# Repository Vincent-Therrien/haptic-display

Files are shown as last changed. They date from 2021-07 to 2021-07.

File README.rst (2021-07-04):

haptic-display
==============

A haptic display prototype for displaying tactile graphics

*Haptic* or *tactile* displays are designed to make images accessible for
visually impaired people. A surface acts as a screen whose elements can be
elevated or lowered to compose pictures accessible through touch.

High prices make this technology unaffordable to many consumers. This project
demonstrates a haptic display prototype with a low manufacturing cost
(inferior to 100 Canadian dollars) that achieves a ten by ten pixel resolution.

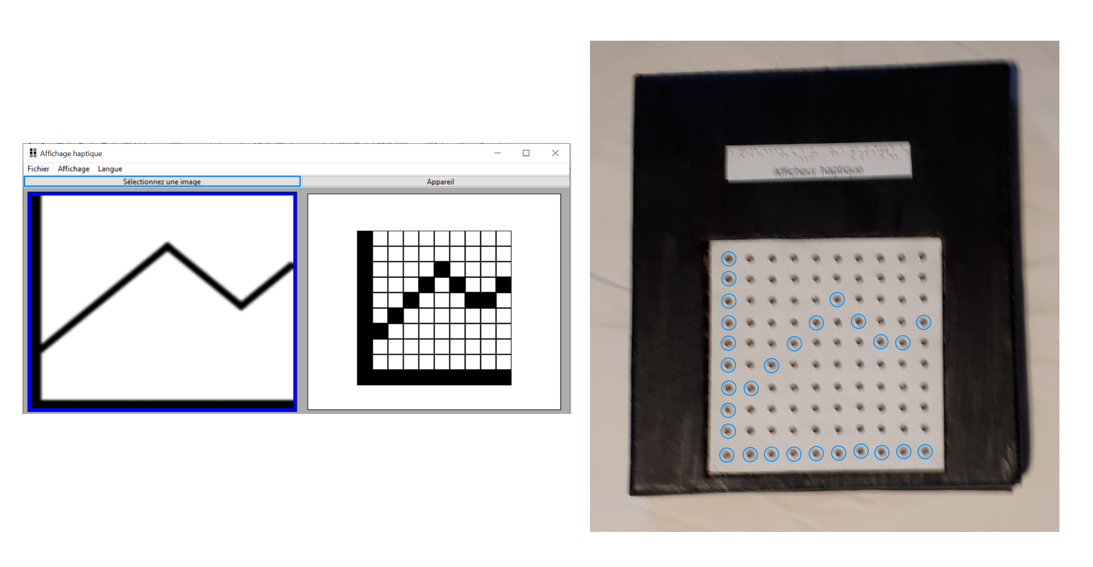
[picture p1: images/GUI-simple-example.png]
Haptic display demonstration with the application and the device


   Use case of the haptic display. The GUI (left) is used to select an image
   and adapt it to the display's resolution. The device (right) displays the
   image - picture elements in high position are highlighted with blue circles.

Project Components
------------------

The project comprises a *device* that displays images and a
*software application* used to upload images to the device. More precisely,

- The device is made of three modules:

  - A *mechanism* controlled with electrical motors manipulates the position
    of picture elements on the display.
  - An *electrical circuit* controls the rotation of motors through H-bridges.
    The circuit plans are available in the "device" directory.
  - An *embedded program* executed on a microcontroller controls power supply

- The application contains two main modules:

  - A graphical user interface, fully accessible with a keyboard and
    compatible with screen readers, is used to select images.
  - An OpenCV-based image manipulation script modifies images to adapt them
    to the display's resolution

Running the Application
-----------------------

The software application is multi-platform and can be used on any system that
support Python, WxWidgets and OpenCV. To run it, go the the
"haptic-display/application" directory, install all required
components (in a virtual environment, preferably) and launch the script
"haptic.py". On Windows,

.. code-block::

   py -m venv venv
   venv\Scripts\activate
   pip install -r application\requirements.txt
   py application/haptic.py

On UNIX,

.. code-block::

   python3 -m venv venv
   source venv/bin/activate
   pip install -r application/requirements.txt
   py application/haptic.py

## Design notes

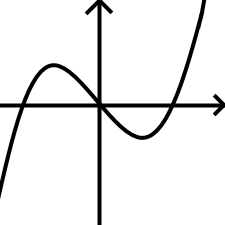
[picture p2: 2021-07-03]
application/assets/examples/third_degree.png

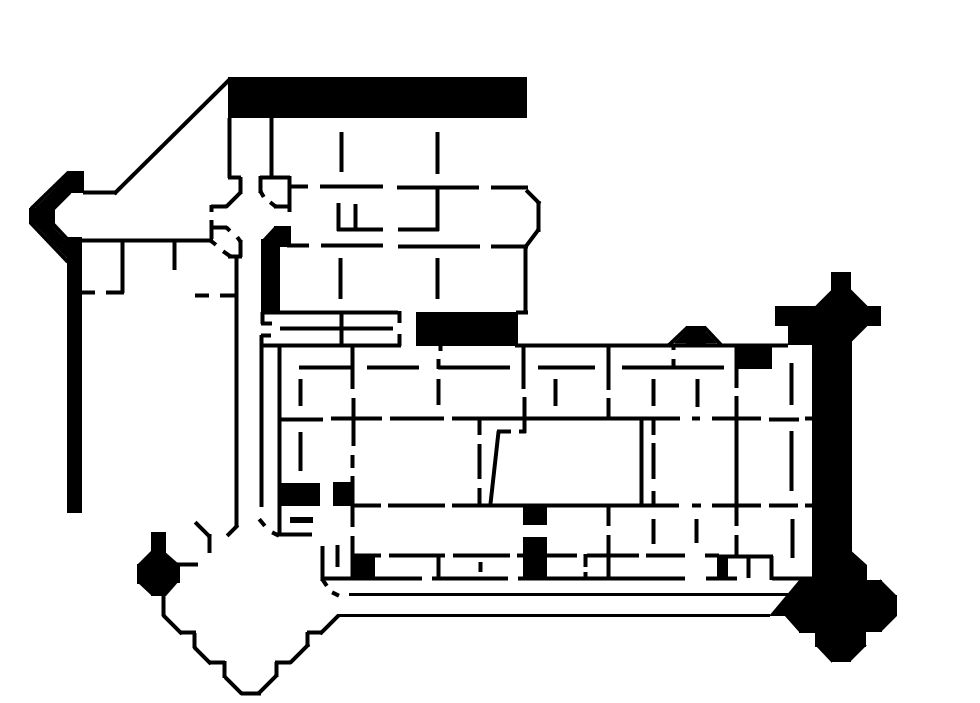
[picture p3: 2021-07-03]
application/assets/examples/mbam_floor_plan.png

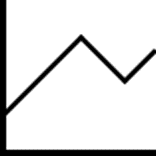
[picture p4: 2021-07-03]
application/assets/examples/linear.png

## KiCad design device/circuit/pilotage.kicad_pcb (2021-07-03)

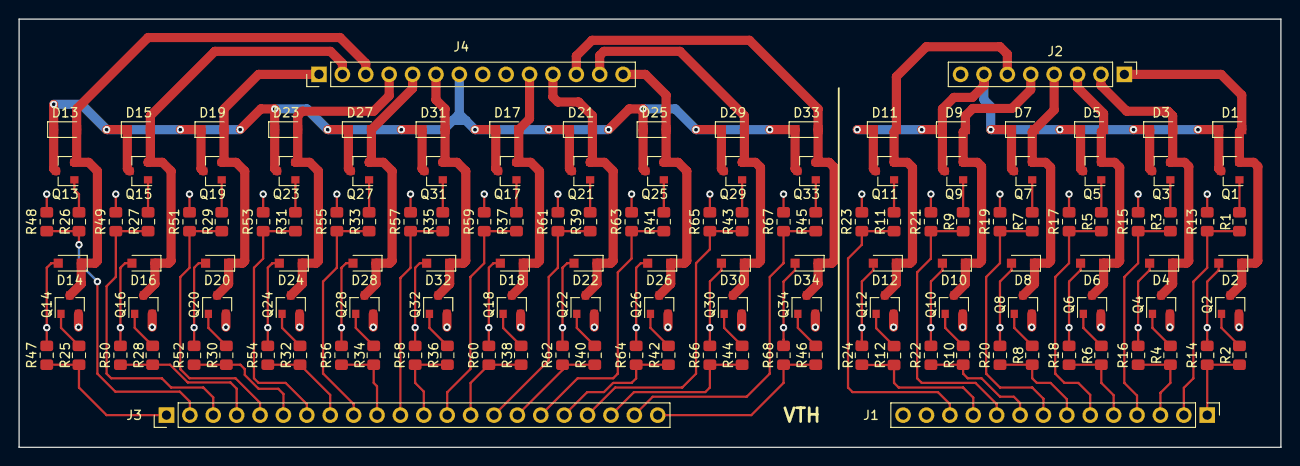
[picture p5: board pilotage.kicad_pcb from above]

Board: 2 copper layers, 137.0 x 46.5 mm, 140 parts (0 on the bottom side), 88 nets.

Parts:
D1, D2, D3, D4, D5, D6, D7, D8, D9, D10, D11, D12, D13, D14, D15, D16, D17, D18, D19, D20, D21, D22, D23, D24, D25, D26, D27, D28, D29, D30, D31, D32, D33, D34: 1N4148; D_SOD-323_HandSoldering
J1, J4: Conn_01x14_Male; PinHeader_1x14_P2.54mm_Vertical
J2: Conn_01x08_Male; PinHeader_1x08_P2.54mm_Vertical
J3: Conn_01x22_Male; PinHeader_1x22_P2.54mm_Vertical
Q1, Q2, Q3, Q4, Q5, Q6, Q7, Q8, Q9, Q10, Q11, Q12, Q13, Q14, Q15, Q16, Q17, Q18, Q19, Q20, Q21, Q22, Q23, Q24, Q25, Q26, Q27, Q28, Q29, Q30, Q31, Q32, Q33, Q34: Q_NMOS_GSD; SOT-23
R1, R2, R3, R4, R5, R6, R7, R8, R9, R10, R11, R12, R25, R26, R27, R28, R29, R30, R31, R32, R33, R34, R35, R36, R37, R38, R39, R40, R41, R42, R43, R44, R45, R46: 51; R_0805_2012Metric_Pad1.15x1.40mm_HandSolder
R13, R14, R15, R16, R17, R18, R19, R20, R21, R22, R23, R24, R47, R48, R49, R50, R51, R52, R53, R54, R55, R56, R57, R58, R59, R60, R61, R62, R63, R64, R65, R66, R67, R68: 20k; R_0805_2012Metric_Pad1.15x1.40mm_HandSolder

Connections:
+6V: D1.1, D3.1, D5.1, D7.1, D9.1, D11.1, J2.7, Q1.3, Q3.3, Q5.3, Q7.3, Q9.3, Q11.3
+7.5V: D13.1, D15.1, D17.1, D19.1, D21.1, D23.1, D25.1, D27.1, D29.1, D31.1, D33.1, J4.7, Q13.3, Q15.3, Q17.3, Q19.3, Q21.3, Q23.3, Q25.3, Q27.3, Q29.3, Q31.3, Q33.3
GND: D2.2, D4.2, D6.2, D8.2, D10.2, D12.2, D14.2, D16.2, D18.2, D20.2, D22.2, D24.2, D26.2, D28.2, D30.2, D32.2, D34.2, J1.14, J2.8, J4.8, Q2.2, Q4.2, Q6.2, Q8.2, Q10.2, Q12.2, Q14.2, Q16.2, Q18.2, Q20.2, Q22.2, Q24.2, Q26.2, Q28.2, Q30.2, Q32.2, Q34.2, R13.2, R14.2, R15.2, R16.2, R17.2, R18.2, R19.2, R20.2, R21.2, R22.2, R23.2, R24.2, R47.2, R48.2, R49.2, R50.2, R51.2, R52.2, R53.2, R54.2, R55.2, R56.2, R57.2, R58.2, R59.2, R60.2, R61.2, R62.2, R63.2, R64.2, R65.2, R66.2, R67.2, R68.2
unnamed: J1.1, R2.2, R14.1
unnamed: J1.2, R1.2, R13.1
unnamed: J1.3, R4.2, R16.1
unnamed: J1.4, R3.2, R15.1
unnamed: J1.5, R6.2, R18.1
unnamed: J1.6, R5.2, R17.1
unnamed: J1.7, R8.2, R20.1
unnamed: J1.8, R7.2, R19.1
unnamed: J1.9, R10.2, R22.1
unnamed: J1.10, R9.2, R21.1
unnamed: J1.11, R12.2, R24.1
unnamed: J1.12, R11.2, R23.1
unnamed: J3.1, R25.2, R47.1
unnamed: J3.2, R26.2, R48.1
unnamed: J3.3, R27.2, R49.1
unnamed: J3.4, R28.2, R50.1
unnamed: J3.5, R29.2, R51.1
unnamed: J3.6, R30.2, R52.1
unnamed: J3.7, R31.2, R53.1
unnamed: J3.8, R32.2, R54.1
unnamed: J3.9, R33.2, R55.1
unnamed: J3.10, R34.2, R56.1
unnamed: J3.11, R35.2, R57.1
unnamed: J3.12, R36.2, R58.1
unnamed: J3.13, R37.2, R59.1
unnamed: J3.14, R38.2, R60.1
unnamed: J3.15, R39.2, R61.1
unnamed: J3.16, R40.2, R62.1
unnamed: J3.17, R41.2, R63.1
unnamed: J3.18, R42.2, R64.1
unnamed: J3.19, R43.2, R65.1
unnamed: J3.20, R44.2, R66.1
unnamed: J3.21, R45.2, R67.1
unnamed: J3.22, R46.2, R68.1
c1b: Q4.1, R4.1
c1h: Q3.1, R3.1
c2b: Q6.1, R6.1
c2h: Q5.1, R5.1
c3b: Q8.1, R8.1
c3h: Q7.1, R7.1
c4b: Q10.1, R10.1
c4h: Q9.1, R9.1
c5b: Q12.1, R12.1
c5h: Q11.1, R11.1
cb: Q2.1, R2.1
ch: Q1.1, R1.1
d1b: Q18.1, R38.1
d1h: Q17.1, R37.1
d2b: Q22.1, R40.1
d2h: Q21.1, R39.1
d3b: Q26.1, R42.1
d3h: Q25.1, R41.1
d4b: Q30.1, R44.1
d4h: Q29.1, R43.1
d5b: Q34.1, R46.1
d5h: Q33.1, R45.1
g1b: Q16.1, R28.1
g1h: Q15.1, R27.1
g2b: Q20.1, R30.1
g2h: Q19.1, R29.1
g3b: Q24.1, R32.1
g3h: Q23.1, R31.1
g4b: Q28.1, R34.1
g4h: Q27.1, R33.1
g5b: Q32.1, R36.1
g5h: Q31.1, R35.1
moteur_c_1_b: D3.2, D4.1, J2.2, Q3.2, Q4.3
moteur_c_2_b: D5.2, D6.1, J2.3, Q5.2, Q6.3
moteur_c_3_b: D7.2, D8.1, J2.4, Q7.2, Q8.3
moteur_c_4_b: D9.2, D10.1, J2.5, Q9.2, Q10.3
moteur_c_5_b: D11.2, D12.1, J2.6, Q11.2, Q12.3
moteur_c_a: D1.2, D2.1, J2.1, Q1.2, Q2.3
moteur_d_1_b: D17.2, D18.1, J4.10, Q17.2, Q18.3
moteur_d_2_b: D21.2, D22.1, J4.11, Q21.2, Q22.3
moteur_d_3_b: D25.2, D26.1, J4.14, Q25.2, Q26.3
moteur_d_4_b: D29.2, D30.1, J4.13, Q29.2, Q30.3
moteur_d_5_b: D33.2, D34.1, J4.12, Q33.2, Q34.3
moteur_g_1_b: D15.2, D16.1, J4.2, Q15.2, Q16.3
moteur_g_2_b: D19.2, D20.1, J4.1, Q19.2, Q20.3
moteur_g_3_b: D23.2, D24.1, J4.4, Q23.2, Q24.3
moteur_g_4_b: D27.2, D28.1, J4.5, Q27.2, Q28.3
moteur_g_5_b: D31.2, D32.1, J4.6, Q31.2, Q32.3
moteur_s_a: D13.2, D14.1, J4.3, Q13.2, Q14.3
sb: Q14.1, R25.1
sh: Q13.1, R26.1

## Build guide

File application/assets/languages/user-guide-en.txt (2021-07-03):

User Guide

Select an image with Ctrl+O and send it to the connected
device by pressing Enter.

Subdivide the image into smaller regions by pressing a number key
and navigate around subdivisions with directional arrows.

Close this menu with Ctrl+X.

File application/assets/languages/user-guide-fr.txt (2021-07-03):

Guide d'utilisation

Sélectionnez une image avec la combinaison Ctrl+O et envoyez-là vers
l'appareil connecté en appuyant sur la touche "Entrée".

Subdivisez une image en régions plus petites en appuyant sur une touche
correspondant à un nombre et naviguer entre les sous-divisions avec les
flèches directionnelles.

Fermez cette fenêtre avec la combinaison Ctrl+X.

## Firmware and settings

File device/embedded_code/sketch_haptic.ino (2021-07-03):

// File: sketch_haptic.ino
//
// This program is designed to control electric motors in a haptic
// display. It is intended to run on an arduino-compatible
// microcontroller.
//
// Vincent Therrien <vincent.therrien@polymtl.ca>

// General
#define N_MOTORS 15
#define N_COLS 10
#define N_ROWS 10

// Transmissions
#define DEVICE_INFO "00000000_10x10"
#define BUFFER_SIZE 128
#define HEADER_SIZE 8
char rx_buffer[BUFFER_SIZE] = {};
int new_byte_index = 0;
bool rx_complete = false;

typedef struct motorGPIO {
  int CWpin;
  int CCWpin;
} motorGPIO;

const motorGPIO indexToMotorGPIO[N_MOTORS] = {
  // central motors
  motorGPIO{4,  5},  // 0
  motorGPIO{6,  7},  // 1
  motorGPIO{8,  9},  // 2
  motorGPIO{10, 11}, // 3
  motorGPIO{12, 13}, // 4
  // lateral motors (push first, pull second)
  motorGPIO{32, 30}, // 5
  motorGPIO{25, 23}, // 6
  motorGPIO{28, 26}, // 7
  motorGPIO{29, 27}, // 8
  motorGPIO{36, 34}, // 9
  motorGPIO{33, 31}, // 10
  motorGPIO{40, 38}, // 11
  motorGPIO{37, 35}, // 12
  motorGPIO{44, 42}, // 13
  motorGPIO{41, 39}, // 14
};
motorGPIO centralCommon = {3, 2};
motorGPIO lateralCommon = {24, 22};

char cells[N_ROWS][N_COLS];

// HAPTIC GENERAL FUNCTIONS
void change_motor_rotation(int torque, int motor_ID){
  // stop
  if (!torque){
    digitalWrite(indexToMotorGPIO[motor_ID].CWpin, LOW);
    digitalWrite(indexToMotorGPIO[motor_ID].CCWpin, LOW);
    if (motor_ID < 5){
      digitalWrite(centralCommon.CWpin, LOW);
      digitalWrite(centralCommon.CCWpin, LOW);
    }
    else {
      digitalWrite(lateralCommon.CWpin, LOW);
      digitalWrite(lateralCommon.CCWpin, LOW);
    }
  }
  // CW
  if (torque == 1){
    digitalWrite(indexToMotorGPIO[motor_ID].CWpin, HIGH);
    digitalWrite(indexToMotorGPIO[motor_ID].CCWpin, LOW);
    if (motor_ID < 5){
      digitalWrite(centralCommon.CWpin, HIGH);
      digitalWrite(centralCommon.CCWpin, LOW);
    }
    else {
      digitalWrite(lateralCommon.CWpin, HIGH);
      digitalWrite(lateralCommon.CCWpin, LOW);
    }
  }
  // CCW
  if (torque == -1){
    digitalWrite(indexToMotorGPIO[motor_ID].CWpin, LOW);
    digitalWrite(indexToMotorGPIO[motor_ID].CCWpin, HIGH);
    if (motor_ID < 5){
      digitalWrite(centralCommon.CWpin, LOW);
      digitalWrite(centralCommon.CCWpin, HIGH);
    }
    else {
      digitalWrite(lateralCommon.CWpin, LOW);
      digitalWrite(lateralCommon.CCWpin, HIGH);
    }
  }
  delay(2);
}
void motor_push(int row){
  int lateralDirection = row % 2 == 0 ? 1 : -1;
  int lateralMotorID = row + (N_COLS / 2);
  change_motor_rotation(lateralDirection, lateralMotorID);
  delay(80);
  change_motor_rotation(0, lateralMotorID);
}
void motor_pull_lightly(int row){
  int lateralDirection = row % 2 == 0 ? -1 : 1;
  int lateralMotorID = row + (N_COLS / 2);
  change_motor_rotation(lateralDirection, lateralMotorID);
  delay(30);
  change_motor_rotation(0, lateralMotorID);
}
void motor_pull_complete(int row){
  int lateralDirection = row % 2 == 0 ? -1 : 1;
  int lateralMotorID = row + (N_COLS / 2);
  change_motor_rotation(lateralDirection, lateralMotorID);
  delay(100);
  change_motor_rotation(0, lateralMotorID);
  // push al little to avoid locking the machanism
  change_motor_rotation(-lateralDirection, lateralMotorID);
  delay(10);
  change_motor_rotation(0, lateralMotorID);
}
void elevate_col(int col){
  int centralDirection = col % 2 == 0 ? -1 : 1;
  int centralMotorID = col / 2;
  change_motor_rotation(centralDirection, centralMotorID);
  delay(100);
  change_motor_rotation(0, centralMotorID);
}
void bring_down(int col){
  int centralDirection = col % 2 == 0 ? 1 : -1;
  int centralMotorID = col / 2;
  change_motor_rotation(centralDirection, centralMotorID);
  delay(10);
  change_motor_rotation(0, centralMotorID);
}

// HAPTIC TASKS
void send_status(){
  Serial.println(DEVICE_INFO);
}
void erase(){
  for (int row = 0; row < N_ROWS; row++){
    motor_pull_complete(row);
  }

  
}
void display_cells(){
  erase();
  // Display row by row.
  for (int row = 0; row < N_ROWS; row++){
    // Check if cells in the row need to be raised.
    bool is_empty = true;
    for (int probe = 0; probe < N_COLS; probe++){
      if (cells[row][probe]){
        is_empty = false;
      }
    }
    // If not empty, must do operations
    if (!is_empty){
      // 1. Push to maximum
      motor_push(row);
      // 2. Raise columns
      for (int col = 0; col < N_COLS; col++){
        if (cells[row][col]){
          elevate_col(col);
          bring_down(col);
        }
      }
      // 3. Pull lightly
      motor_pull_lightly(row);
      // 4. Raise again
      for (int col = 0; col < N_COLS; col++){
        if (cells[row][col]){
          elevate_col(col);
          bring_down(col);
        }
      }
    }
    else {
      motor_pull_complete(row);
    }
  }
}
// 1: must send status
// 2: must display
// 3: must erase
int decode_message(){
  // Status request
  if (memcmp("status__", rx_buffer, HEADER_SIZE) == 0){
    return 1;
  }
  else if (memcmp("cells___", rx_buffer, HEADER_SIZE) == 0){
    for (int i = 0; i < N_COLS*N_ROWS; i++){
      if (rx_buffer[i + HEADER_SIZE] == 'h'){
        cells[i / N_ROWS][i - ((i / N_COLS) * N_ROWS)] = 1;
      }
      else {
        cells[i / N_ROWS][i - ((i / N_COLS) * N_ROWS)] = 0;
      }
    }
    return 2;
  }
  else if (memcmp("erase___", rx_buffer, HEADER_SIZE) == 0){
    return 3;
  }
  return 0;
}

// ARDUINO-SPECIFIC FUNCTIONS
void setup() {
  Serial.begin(9600);
  for (int i = 0; i < N_MOTORS; i++){
    pinMode(indexToMotorGPIO[i].CWpin, OUTPUT);
    digitalWrite(indexToMotorGPIO[i].CWpin, LOW);
    pinMode(indexToMotorGPIO[i].CCWpin, OUTPUT);
    digitalWrite(indexToMotorGPIO[i].CCWpin, LOW);
  }
  pinMode(centralCommon.CWpin, OUTPUT);
  digitalWrite(centralCommon.CWpin, LOW);
  pinMode(centralCommon.CCWpin, OUTPUT);
  digitalWrite(centralCommon.CCWpin, LOW);

  pinMode(lateralCommon.CWpin, OUTPUT);
  digitalWrite(lateralCommon.CWpin, LOW);
  pinMode(lateralCommon.CCWpin, OUTPUT);
  digitalWrite(lateralCommon.CCWpin, LOW);
}
void loop() {
  if (rx_complete) {
    int action = decode_message();
    if (action == 1){
      send_status();
    }
    else if (action == 2){
      display_cells();
    }
    else if (action == 3){
      erase();
    }
    for (int i = 0; i < BUFFER_SIZE; i++){
      rx_buffer[i] = 0;
    }
    new_byte_index = 0;
    rx_complete = false;
  }
}
void serialEvent() {
  while (Serial.available()) {
    char inChar = (char)Serial.read();
    rx_buffer[new_byte_index] = inChar;
    new_byte_index++;
    if (inChar == '\n' || new_byte_index >= 128) {
      rx_complete = true;
    }
  }
}

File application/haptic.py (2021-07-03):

"""Haptic display front-end application for desktop.

This program offers an accessible interface for uploading images to a
haptic display. Please install required packages in the "requirement.txt"
file to launch the application.

Vincent Therrien. <vincent.therrien@polymtl.ca>

"""

import os
import wx
import cv2
import json
import serial
from svglib.svglib import svg2rlg
from reportlab.graphics import renderPM

def scale_bitmap(bitmap: wx.Image, width: int, height: int) -> wx.Image:
    """Scale a WxWidget image and return the modified bitmap.
    
    Param:
        bitmap (wx.Image): Source image
        width (int): Width of the image in pixels
        height (int): Height of the image in pixels
    
    Returns:
        wx.Image: Modified bitmap
    
    """
    image = bitmap.ConvertToImage()
    image = image.Scale(width, height, wx.IMAGE_QUALITY_HIGH)
    result = wx.Bitmap(image)
    return result

class DeviceInfo(wx.Frame):
    """A text widget that shows up to  to display device information."""
    def __init__(self, windowTitle, strings):
        wx.Frame.__init__(self, None, title=windowTitle)
        content = ""
        for key, value in strings.items():
            content += key + "\t\t"
            if len(key) < 7:
                content += "\t"
            content += value + "\n\n"
        lbl = wx.StaticText(self, style = wx.ALIGN_LEFT | wx.EXPAND, size = (500, 500))
        lbl.SetLabel(content)
        self.Centre()
        self.Bind(wx.EVT_KEY_DOWN, self.OnKey)
    
    def OnKey(self, event):
        # Ctrl + x
        if event.ControlDown() and event.GetKeyCode() == 88:
            self.Close()
        else:
            event.Skip()

class HelpWidget(wx.Frame):
    """A text widget to invoke the user guide."""
    def __init__(self, windowTitle, language):
        wx.Frame.__init__(self, None, title=windowTitle)
        content = ""
        if language == "en":
            with open("assets/languages/user-guide-en.txt", encoding='utf8') as f:
                content = f.read()
        elif language == "fr":
            with open("assets/languages/user-guide-fr.txt", encoding='utf8') as f:
                content = f.read()
        lbl = wx.StaticText(self, style = wx.ALIGN_LEFT | wx.EXPAND, size = (500, 500))
        lbl.SetLabel(content)
        self.Centre()
        self.Bind(wx.EVT_KEY_DOWN, self.OnKey)
    
    def OnKey(self, event):
        # Ctrl + x
        if event.ControlDown() and event.GetKeyCode() == 88:
            self.Close()
        else:
            event.Skip()

class MainFrame(wx.Frame):
    """Application window containing most functionalities.
    
    The application is split in two main parts: a image preview on
    the left and a processed image on the right.

    Attributes:
        settings (Dict): General settings retrieved from a text file
        lexicon (Dict): Words used in the application for supported languages
        nRow (int): Number of rows on the physical device
        nCol (int): Number of columns on the physical device
        cellArray (List): Two dimensional array of taxels to display
        imagePath (str): File path to the image to display
        subImages (List): list of images in the preview
        focusRectIndex (List): Coordinates of the subregion in focus
        dimension (int): Dimension of the preview
    
    """
    def __init__(self, *args, **kwargs):
        super(MainFrame, self).__init__(*args, **kwargs)
        # Retrieve user settings
        self.settings = {}
        with open('assets/settings.json') as f:
            self.settings = json.load(f)
        self.lexicon = {}
        self.setLanguage()
        # Runtime data
        self.nRow = 10
        self.nCol = 10
        self.cellArray = []
        for row in range(self.nRow):
            new_row = []
            for cell in range(self.nCol):
                new_row.append(0)
            self.cellArray.append(new_row)
        self.imagePath = None
        self.subImages = []
        self.focusRectIndex = [0, 0]
        self.dimension = 1
        self.serialPort = None
        self.connectUtility = wx.CallLater(1000, self.connect)
        self.objectName = ""
        # Create application components.
        self.SetIcon(wx.Icon("assets/icon.png"))
        self.Centre()
        self.InitUI()
        self.SetTitle(self.lexicon["Title"])
        self.SetSize((900, 450))
        self.Centre()
        self.Bind(wx.EVT_PAINT, self.OnPaint)
        self.Bind(wx.EVT_SIZE, self.refresh)
        self.Bind(wx.EVT_KEY_DOWN, self.OnKey)
        self.Maximize(True)
    
    def refresh(self, arg):
        """Redraw all elements in the application."""
        self.Refresh()
        self.drawImage()
        self.refreshCells()
        self.SetFocus()
    
    def OnKey(self, event):
        """Perform an operation given a pressed key."""
        # CTRL + open (O)
        if event.ControlDown() and event.GetKeyCode() == 79:
            self.OnOpen(event)
        # CTRL help (H)
        elif event.ControlDown() and event.GetKeyCode() == 72:
            self.onHelp()
        # CTRL info (I)
        elif event.ControlDown() and event.GetKeyCode() == 73:
            self.OnDeviceInfo(event)
        # CTRL erase (E)
        elif event.ControlDown() and event.GetKeyCode() == 69:
            self.erase()
        # CTRL delete (X)
        elif event.ControlDown() and event.GetKeyCode() == 88:
            self.Close()
        # numbers
        elif event.GetKeyCode() > 48 and event.GetKeyCode() < 58:
            self.dimension = event.GetKeyCode() - 48
            self.focusRectIndex = [0, 0]
            self.refreshCells()
            self.refresh(None)
        # arrows
        elif event.GetKeyCode() == wx.WXK_DOWN:
            self.navigate('down')
        elif event.GetKeyCode() == wx.WXK_UP:
            self.navigate('up')
        elif event.GetKeyCode() == wx.WXK_LEFT:
            self.navigate('left')
        elif event.GetKeyCode() == wx.WXK_RIGHT:
            self.navigate('right')
        # Transmit image
        elif event.GetKeyCode() == wx.WXK_RETURN:
            self.transmit()
        else:
            event.Skip()
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
